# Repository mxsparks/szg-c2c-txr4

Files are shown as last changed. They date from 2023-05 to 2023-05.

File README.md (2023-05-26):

#  SYZYGY TXR4 Carrier-to-Carrier Adapter

A board-to-board connector supporting the high-speed SERDES I/O of two [SYZYGY](https://syzygyfpga.io)-compatible FPGA carrier cards, with an onboard PCIe reference clock.

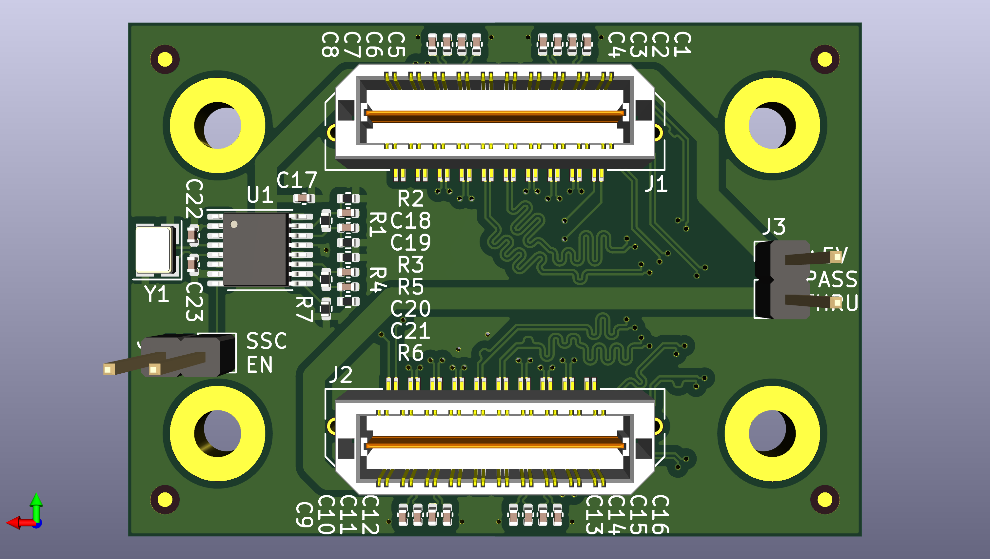
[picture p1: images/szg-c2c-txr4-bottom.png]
Rendering of the component side of a populated SZG-C2C-TXR4 rev.A board

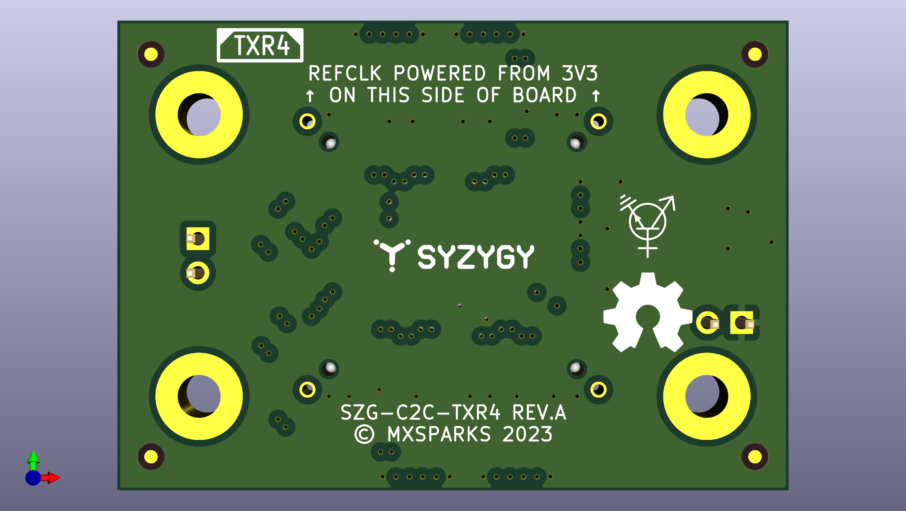
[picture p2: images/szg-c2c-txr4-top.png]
Rendering of the backside of a populated SZG-C2C-TXR4 rev.A board


## Overview

This card is intended as a development tool for high-speed board-to-board communication, e.g. between an Avnet [ZuBoard 1CG](https://www.avnet.com/wps/portal/us/products/avnet-boards/avnet-board-families/zuboard-1cg/zuboard-1cg) and a [ButterStick](https://github.com/butterstick-fpga/butterstick-hardware/blob/main/README.md). It routes the high-speed lanes (4 Tx, 4 Rx) as 100Ω AC-coupled differential pairs and provides an AC-coupled 100 MHz reference clock to both carrier cards. Additionally, it provides DC-coupled routing for the two general-purpose clocks (1 Tx, 1 Rx), 10 single-ended I/Os (routed as 5 differential pairs), and I2C. Jumper J3 allows one carrier card to optionally supply 5V power to the other. Jumper J4 enables spread-spectrum clocking (0.5% downshift).

## Note

This board is not SmartVIO-compatible and does not include a SYZYGY DNA MCU. Double-check that you're using compatible I/O standards on both connected FPGAs.

The high-speed lanes are polarity-inverted and partially lane-reversed, i.e. TX(0,1,2,3)p on J1 are connected to RX(2,3,0,1)n on J2. Depending on your FPGAs, this may limit your PCIe link to x2 instead of x4. It definitely prevents this card from being used to connect two SYZYGY TXR2 ports together (connecting a TXR4 port to a TXR2 port will still work).

## Fabrication

- Dimensions: 50 x 35 x 1.6 mm
- Standard 6-layer stackup from [JLCPCB](https://jlcpcb.com)
- Via in Pad required
- 6mil/6mil (0.15mm) trace/space
- 12mil (0.3mm) minimum drill size, 3mil (0.075mm) annular ring
- Layer In1.Cu: impedance-controlled to 100 Ω differential ± 10%.

## License

© 2023 mxsparks. Licensed under [CERN-OHL-P v2](https://ohwr.org/cern_ohl_p_v2.txt). Connector footprints from [SYZYGYfpga/pcb-templates](https://github.com/SYZYGYfpga/pcb-templates).

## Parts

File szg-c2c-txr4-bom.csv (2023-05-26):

Quantity | Reference Designators | JLCPCB Part # | Description | Manufacturer | Manufacturer Part #
20 | C1,C2,C3,C4,C5,C6,C7,C8,C9,C10,C11,C12,C13,C14,C15,C16,C18,C19,C20,C21 | C1525 | 16V 100nF X7R ±10% 0402 Multilayer Ceramic Capacitors MLCC - SMD/SMT ROHS | Samsung | CL05B104KO5NNNC
1 | C17 | C15195 | 50V 10nF X7R ±10% 0402 Multilayer Ceramic Capacitors MLCC - SMD/SMT ROHS | Samsung | CL05B103KB5NNNC
2 | C22,C23 | C1864375 | 50V 8pF C0G ±1% 0402 Multilayer Ceramic Capacitors MLCC - SMD/SMT ROHS | Murata | GCM1555C1H8R0FA16D
2 | J1,J2 | C3654517 | 40 Position Connector Differential Pair Array, Male Surface Mount Gold | Samtec | QTH-020-01-F-D-DP-A-K-TR
2 | J3,J4 | C390678 | 3A Straight Square Pins 2.5mm 6.1mm 3mm 2 2.54mm Single Row Black Brass 1x2P Plugin,P=2.54mm Pin Headers ROHS | Pinrex | 210-91-02GB01
2 | R1,R4 | C25076 | 62.5mW Thick Film Resistors ±1% 100Ω 0402 Chip Resistor - Surface Mount ROHS | Uniroyal | 0402WGF1000TCE
4 | R2,R3,R5,R6 | C25082 | 62.5mW Thick Film Resistors ±1% 150Ω 0402 Chip Resistor - Surface Mount ROHS | Uniroyal | 0402WGF1500TCE
1 | R7 | C25117 | 62.5mW Thick Film Resistors ±1% 470Ω 0402 Chip Resistor - Surface Mount ROHS | Uniroyal | 0402WGF4700TCE
1 | U1 | C500785 | 200MHz 2 TSSOP-16 Clock Generators / Frequency Synthesizers / PLL ROHS | Diodes Inc. | PI6C557-03LEX
1 | Y1 | C9006 | 25MHz 12pF ±10ppm ±30ppm SMD3225-4P Crystals ROHS | Yangxing Tech | X322525MOB4SI

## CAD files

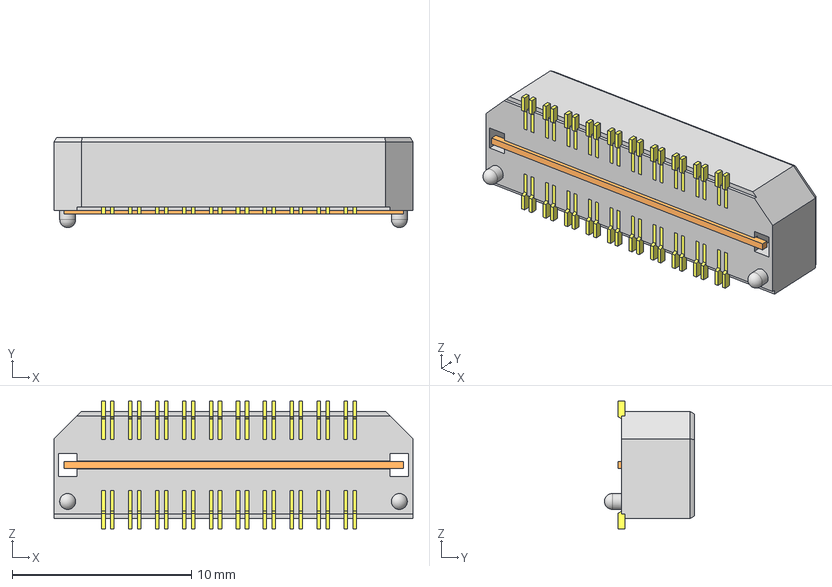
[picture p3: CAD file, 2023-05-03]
3D/QTH-020-01-F-D-DP-A.stp
20.0 x 5.03 x 7.11 mm
_TQTH-020-01-F-D-DP-A_terminal
_T-1S39-01(-020-01-D-DP)_pin
_T-1G1-01_imp

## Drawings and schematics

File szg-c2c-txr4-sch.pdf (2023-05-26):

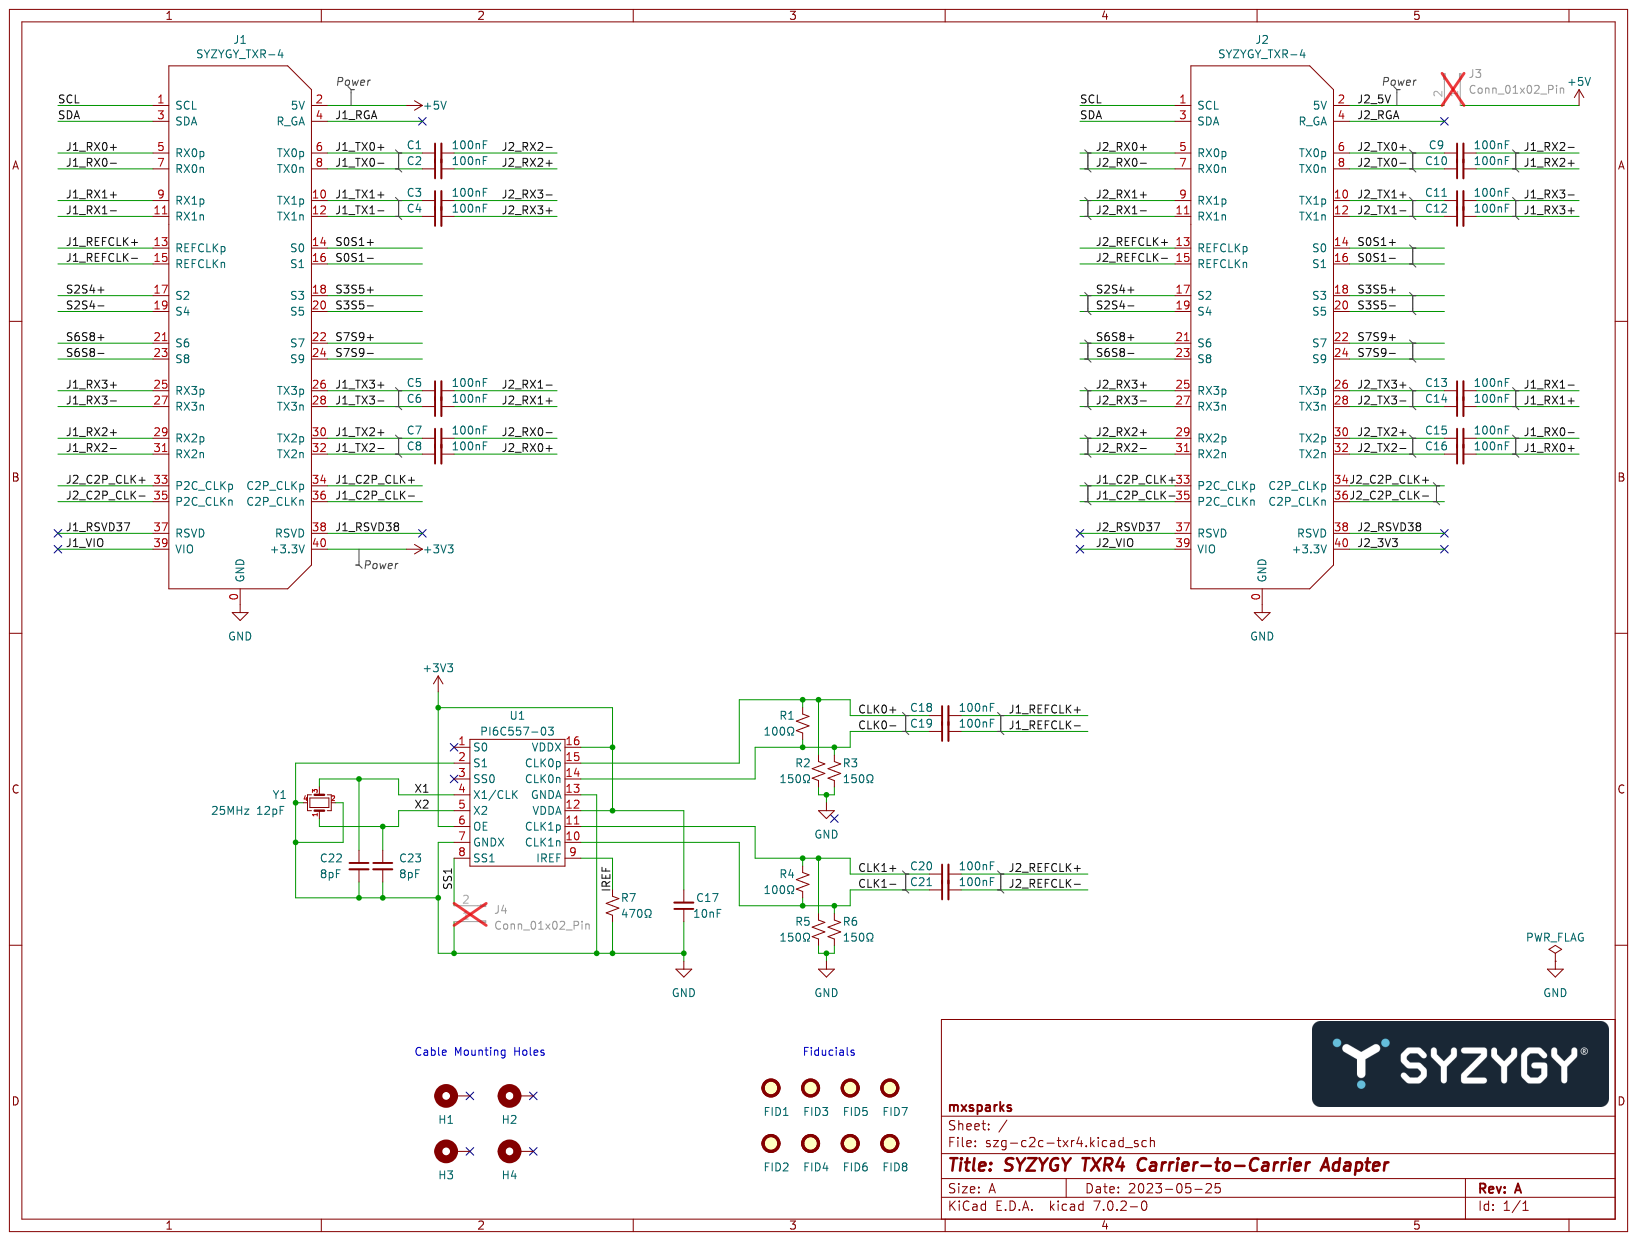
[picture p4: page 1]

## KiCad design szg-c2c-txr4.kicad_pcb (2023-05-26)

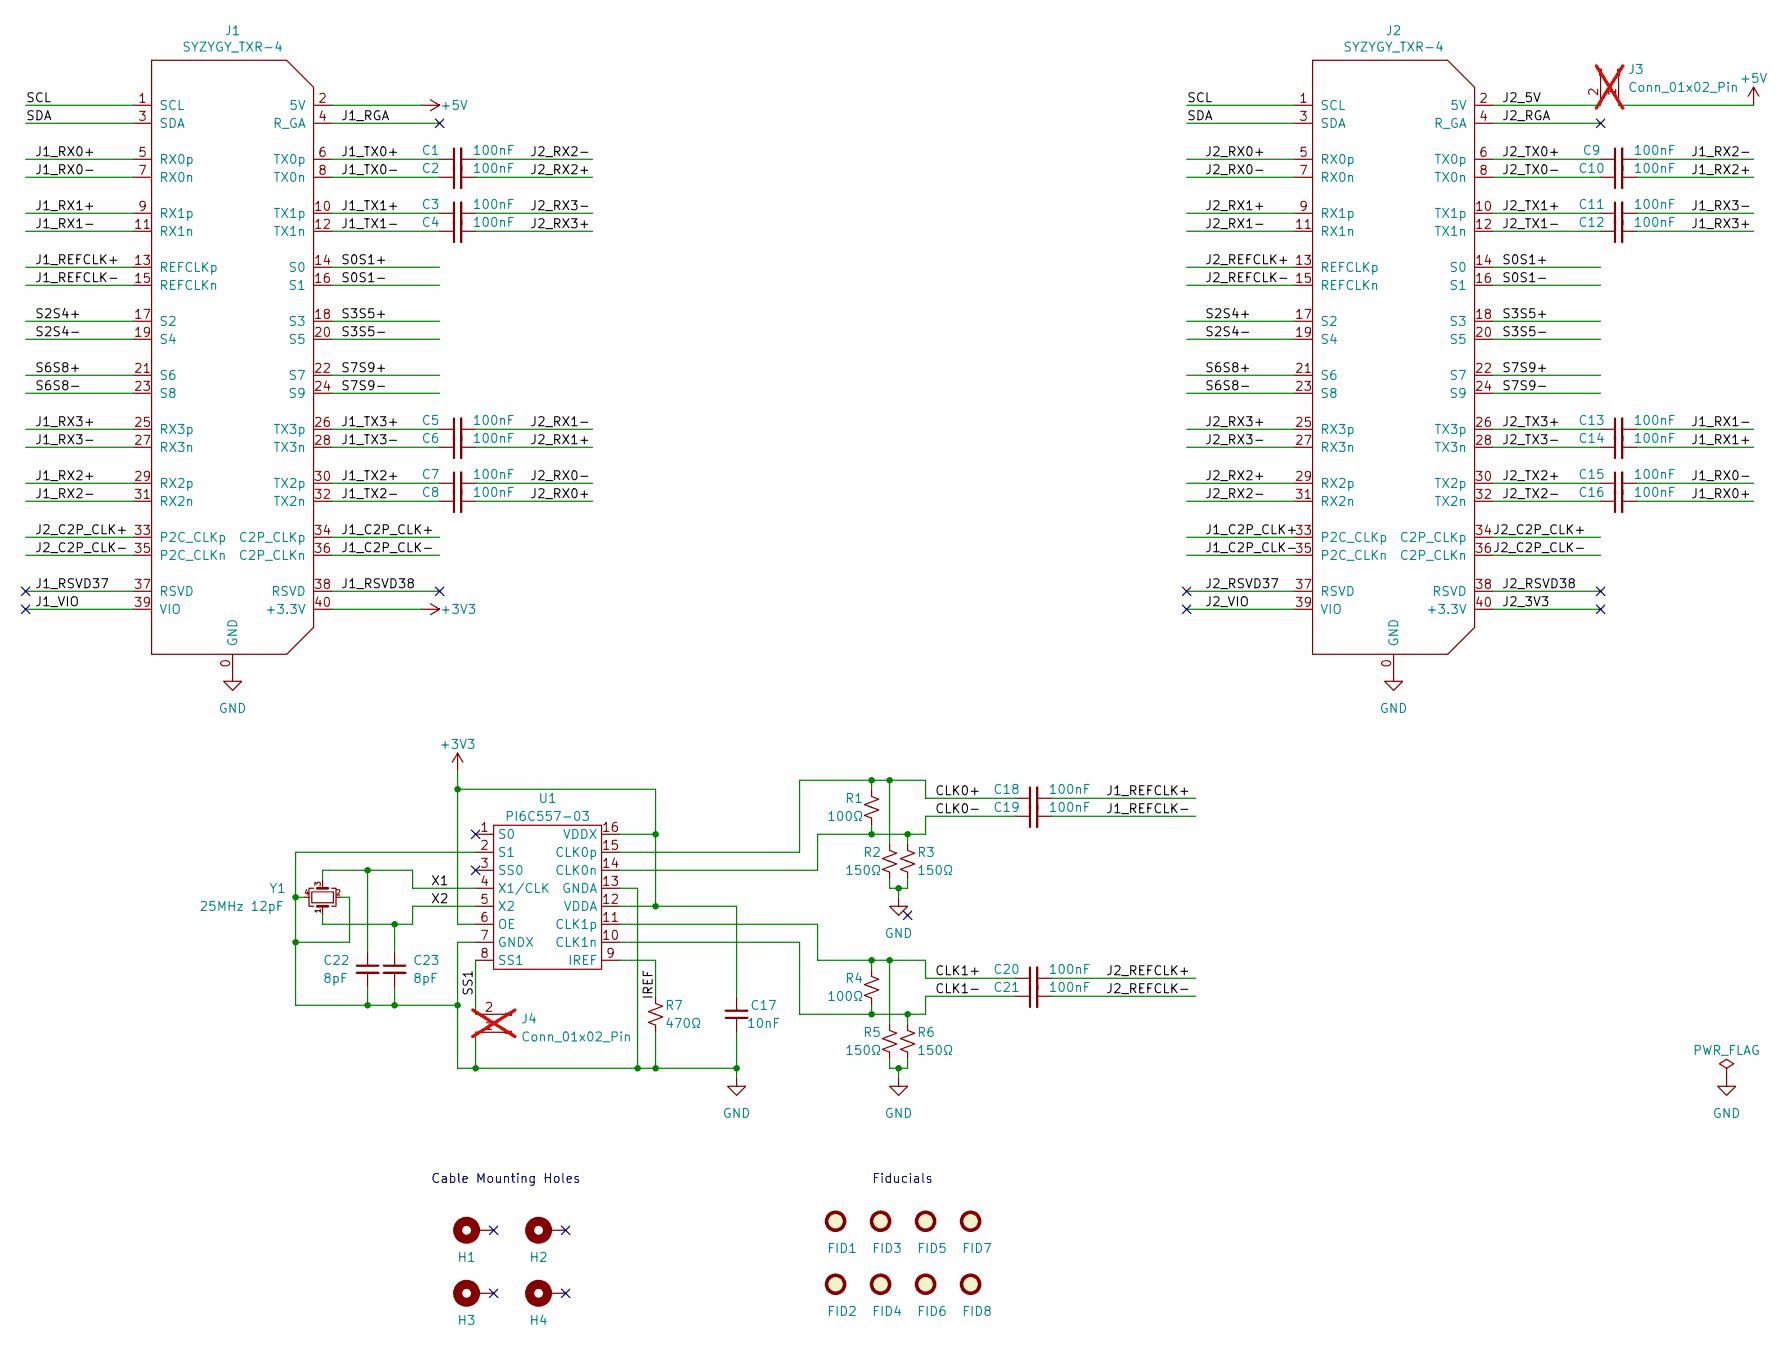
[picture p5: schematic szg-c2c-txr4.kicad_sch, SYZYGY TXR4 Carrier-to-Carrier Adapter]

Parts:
C1, C2, C3, C4, C5, C6, C7, C8, C9, C10, C11, C12, C13, C14, C15, C16, C18, C19, C20, C21: 100nF; C_0402_1005Metric
C17: 10nF; C_0402_1005Metric
C22, C23: 8pF; C_0402_1005Metric
FID1, FID2, FID3, FID4, FID5, FID6, FID7, FID8: Fiducial; Fiducial_1mm_Mask2mm
H1, H2, H3, H4: MountingHole_Pad; MountingHole_3.2mm_M3_6.5mm_Pad_TopBottom
J1, J2: SYZYGY_TXR-4; QTH-020-01-F-D-DP-A; Manufacturer_PN QTH-020-01-F-D-DP-A
J3, J4: Conn_01x02_Pin; PinHeader_1x02_P2.54mm_Vertical; not fitted
R1, R4: 100Ω; R_0402_1005Metric
R2, R3, R5, R6: 150Ω; R_0402_1005Metric
R7: 470Ω; R_0402_1005Metric
U1: PI6C557-03; TSSOP-16_4.4x5mm_P0.65mm
Y1: 25MHz 12pF; Crystal_SMD_3225-4Pin_3.2x2.5mm

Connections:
+3V3: C17.2, J1.40 (+3.3V), U1.6 (OE), U1.12 (VDDA), U1.16 (VDDX)
+5V: J1.2 (5V), J3.1
/CLK0+: C18.1, R1.1, R2.1, U1.15 (CLK0p)
/CLK0-: C19.1, R1.2, R3.1, U1.14 (CLK0n)
/CLK1+: C20.1, R4.1, R5.1, U1.11 (CLK1p)
/CLK1-: C21.1, R4.2, R6.1, U1.10 (CLK1n)
/IREF: R7.1, U1.9 (IREF)
/J1_C2P_CLK+: J1.34 (C2P_CLKp), J2.33 (P2C_CLKp)
/J1_C2P_CLK-: J1.36 (C2P_CLKn), J2.35 (P2C_CLKn)
/J1_REFCLK+: C18.2, J1.13 (REFCLKp)
/J1_REFCLK-: C19.2, J1.15 (REFCLKn)
/J1_RGA: J1.4 (R_GA)
/J1_RSVD37: J1.37 (RSVD)
/J1_RSVD38: J1.38 (RSVD)
/J1_RX0+: C16.2, J1.5 (RX0p)
/J1_RX0-: C15.2, J1.7 (RX0n)
/J1_RX1+: C14.2, J1.9 (RX1p)
/J1_RX1-: C13.2, J1.11 (RX1n)
/J1_RX2+: C10.2, J1.29 (RX2p)
/J1_RX2-: C9.2, J1.31 (RX2n)
/J1_RX3+: C12.2, J1.25 (RX3p)
/J1_RX3-: C11.2, J1.27 (RX3n)
/J1_TX0+: C1.1, J1.6 (TX0p)
/J1_TX0-: C2.1, J1.8 (TX0n)
/J1_TX1+: C3.1, J1.10 (TX1p)
/J1_TX1-: C4.1, J1.12 (TX1n)
/J1_TX2+: C7.1, J1.30 (TX2p)
/J1_TX2-: C8.1, J1.32 (TX2n)
/J1_TX3+: C5.1, J1.26 (TX3p)
/J1_TX3-: C6.1, J1.28 (TX3n)
/J1_VIO: J1.39 (VIO)
/J2_3V3: J2.40 (+3.3V)
/J2_5V: J2.2 (5V), J3.2
/J2_C2P_CLK+: J1.33 (P2C_CLKp), J2.34 (C2P_CLKp)
/J2_C2P_CLK-: J1.35 (P2C_CLKn), J2.36 (C2P_CLKn)
/J2_REFCLK+: C20.2, J2.13 (REFCLKp)
/J2_REFCLK-: C21.2, J2.15 (REFCLKn)
/J2_RGA: J2.4 (R_GA)
/J2_RSVD37: J2.37 (RSVD)
/J2_RSVD38: J2.38 (RSVD)
/J2_RX0+: C8.2, J2.5 (RX0p)
/J2_RX0-: C7.2, J2.7 (RX0n)
/J2_RX1+: C6.2, J2.9 (RX1p)
/J2_RX1-: C5.2, J2.11 (RX1n)
/J2_RX2+: C2.2, J2.29 (RX2p)
/J2_RX2-: C1.2, J2.31 (RX2n)
/J2_RX3+: C4.2, J2.25 (RX3p)
/J2_RX3-: C3.2, J2.27 (RX3n)
/J2_TX0+: C9.1, J2.6 (TX0p)
/J2_TX0-: C10.1, J2.8 (TX0n)
/J2_TX1+: C11.1, J2.10 (TX1p)
/J2_TX1-: C12.1, J2.12 (TX1n)
/J2_TX2+: C15.1, J2.30 (TX2p)
/J2_TX2-: C16.1, J2.32 (TX2n)
/J2_TX3+: C13.1, J2.26 (TX3p)
/J2_TX3-: C14.1, J2.28 (TX3n)
/J2_VIO: J2.39 (VIO)
/S0S1+: J1.14 (S0), J2.14 (S0)
/S0S1-: J1.16 (S1), J2.16 (S1)
/S2S4+: J1.17 (S2), J2.17 (S2)
/S2S4-: J1.19 (S4), J2.19 (S4)
/S3S5+: J1.18 (S3), J2.18 (S3)
/S3S5-: J1.20 (S5), J2.20 (S5)
/S6S8+: J1.21 (S6), J2.21 (S6)
/S6S8-: J1.23 (S8), J2.23 (S8)
/S7S9+: J1.22 (S7), J2.22 (S7)
/S7S9-: J1.24 (S9), J2.24 (S9)
/SCL: J1.1 (SCL), J2.1 (SCL)
/SDA: J1.3 (SDA), J2.3 (SDA)
/SS1: J4.2, U1.8 (SS1)
/X1: C22.1, U1.4 (X1/CLK), Y1.3
/X2: C23.1, U1.5 (X2), Y1.1
GND: C17.1, C22.2, C23.2, J1.0 (GND), J2.0 (GND), J4.1, R2.2, R3.2, R5.2, R6.2, R7.2, U1.2 (S1), U1.7 (GNDX), U1.13 (GNDA), Y1.2, Y1.4

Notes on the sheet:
Cable Mounting Holes
Fiducials

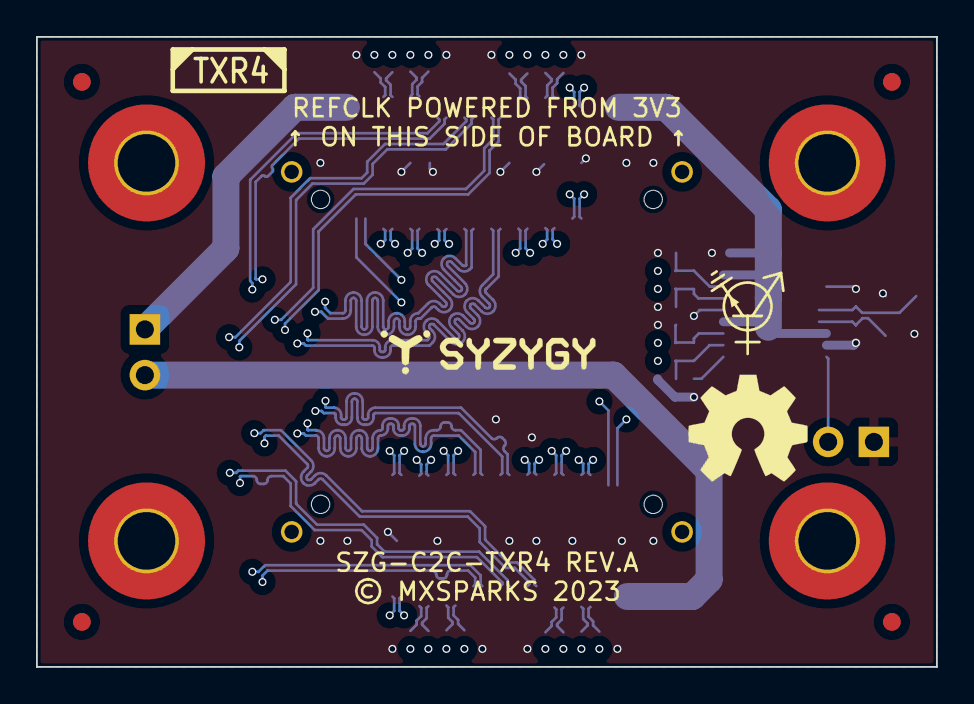
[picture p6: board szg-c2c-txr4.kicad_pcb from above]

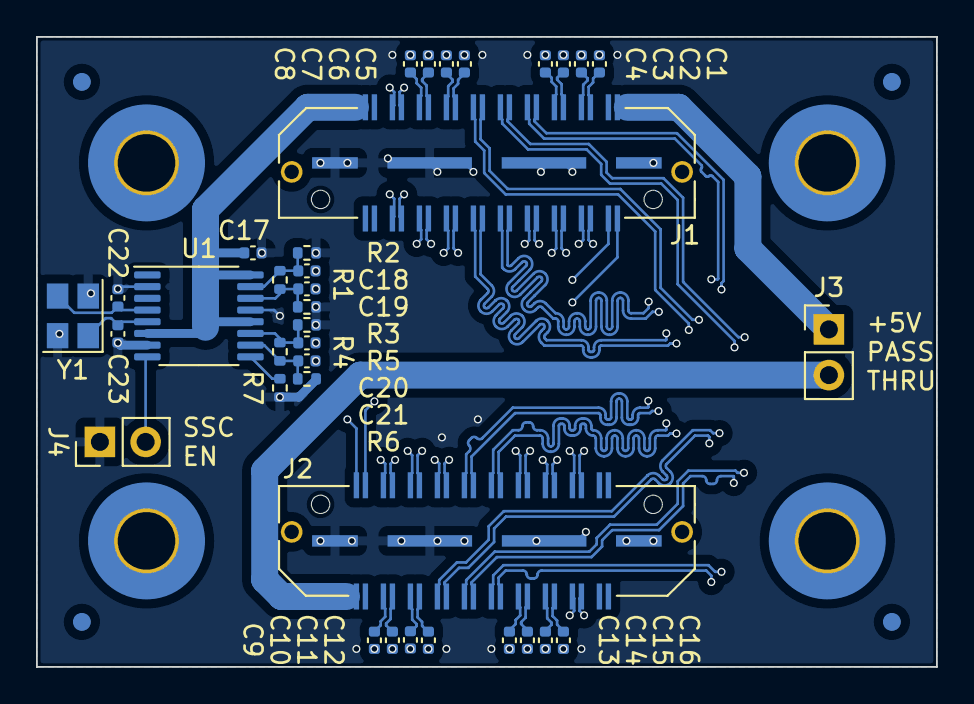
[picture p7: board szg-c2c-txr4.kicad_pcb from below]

Board: 6 copper layers, 50.0 x 35.0 mm, 50 parts (40 on the bottom side), 64 nets.

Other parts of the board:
G**: Transistor-Logo
G**#2: SYZYGY_STD_Logo; SYZYGY_TXR4_Logo

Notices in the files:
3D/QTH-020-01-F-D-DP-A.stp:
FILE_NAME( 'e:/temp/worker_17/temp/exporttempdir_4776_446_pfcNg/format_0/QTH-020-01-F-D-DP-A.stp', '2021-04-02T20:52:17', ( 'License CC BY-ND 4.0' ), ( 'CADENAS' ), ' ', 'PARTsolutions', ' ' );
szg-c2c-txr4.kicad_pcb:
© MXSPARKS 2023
